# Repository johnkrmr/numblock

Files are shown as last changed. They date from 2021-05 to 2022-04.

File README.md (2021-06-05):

# Numblock #
A small 4x5 diy keypad to get into pcb design and custom keyboards.

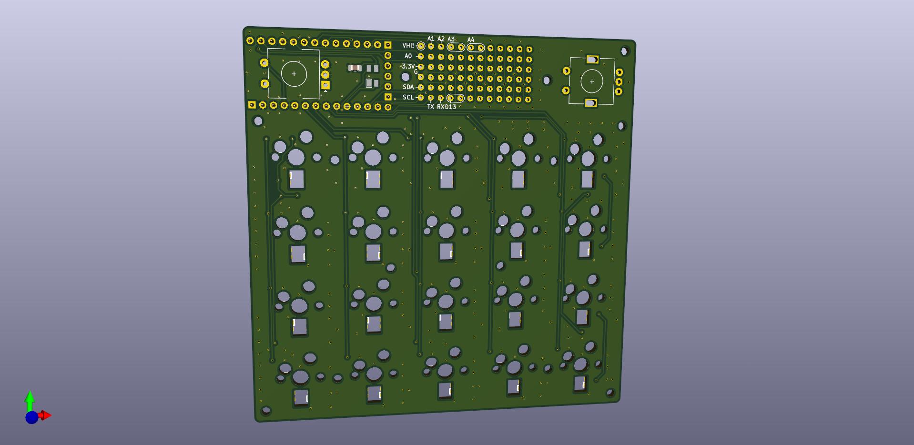
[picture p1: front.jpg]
pcb front
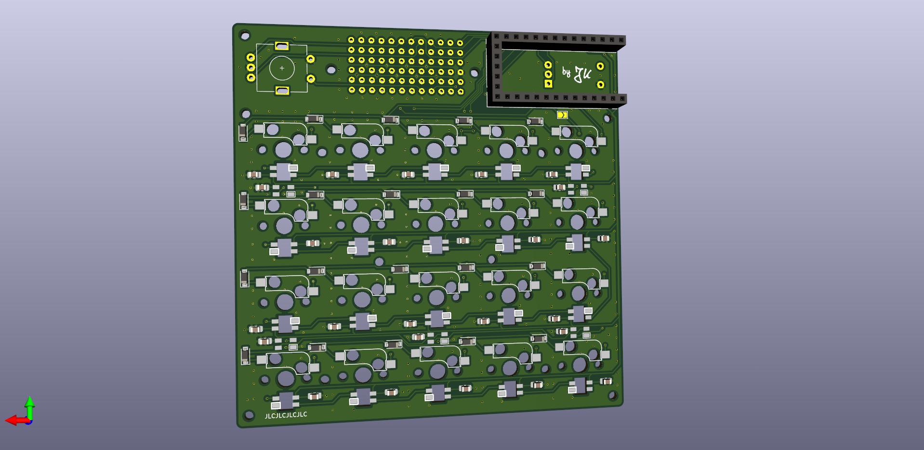
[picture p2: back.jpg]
pcb back
 

## IMPORTANT ##
PCB not tested yet. There's no guarantee that it will work right now!  
Front panel needed to mount 3-pin switches. No files for that provided yet.  
Generally this README and the whole project is far away from being
complete.

## Features ##
- 4x5 keys (cherry mx compatible, hotswappable)
- compatible with variety of Adafruit ItsyBitsy boards:
	- 32u4 (3.3V 8MHz Version!)
	- M4
	- nRF52840
	- RP2040?
	- M0?
- up to 2 rotary encoders (optional)
- indicator RGB led (optional)
- RGB underglow (optional)
- RGB backlight (optional)
- i2c OLED-Display (optional)
- small 'prototyping' area with access to i2c, serial + some analog Pins

## Components ##
- PCB
- 20 1N4148W Diods (SOD123 package)
- 20 hotswap sockets for cherry mx compatible switches
- 20 cherry mx compatible switches (both 3 and 5 pin versions should
work)
- compatible ItsyBitsy controller (cf. features)
- 8 SK6812 mini *HW* RGB LEDs for underglow + top indicator led
- 20 SK6812 mini RGB LEDs for backlight
- 0.1μF 0805 capacitors for each RGB LED (cf. notes)
- up to 2 Alps EC11E rotary encoders
- i2c OLED display, [this
one](https://www.waveshare.com/wiki/0.91inch_OLED_Module) should fit perfectly
- front panel
- some sort of case or an extra back panel
- screws to hold the whole thing together
- rubber feet (otherwise typing won't be much fun)

## Notes ##
### Electronics ###
- 0.1μF capacitors are recommended according to the datasheet. There are many
designs without them. I do not know whether or not they are necessary.
- A resistor on the LED data line between the controller and the first led is
recommended. I forgot to add that on. Here as well many pcbs do not include
them. It should work. [Supposedly](https://learn.adafruit.com/adafruit-neopixel-uberguide/basic-connections) what could happen is that the first LED in the 'chain' gets fried every
once in a while.
- A wireless version could be achieved with the nRF52840 in combination with the [LiIon/LiPoly
Backpack](https://www.adafruit.com/product/2124).

### Software ###
- I experienced some form of 'ghosting' in the upper two rows when setting
columns to *high* and
reading from row pins with *internal pulldowns* (diodes
facing opposite way than shown in schematics). When holding 4
switches down in same row, the 5th one shows as constantly on or
continuously toggling. This does
not seam to appear when setting rows to *low* and reading from columns with *internal
pullups*. So I guess **use internal pullups** for scanning the matrix.

## Resources ##
- [Josef Adamcik's sofle
keyboard](https://josefadamcik.github.io/SofleKeyboard/)
- [KiCad Keyboard Tutorial](https://github.com/ruiqimao/keyboard-pcb-guide)

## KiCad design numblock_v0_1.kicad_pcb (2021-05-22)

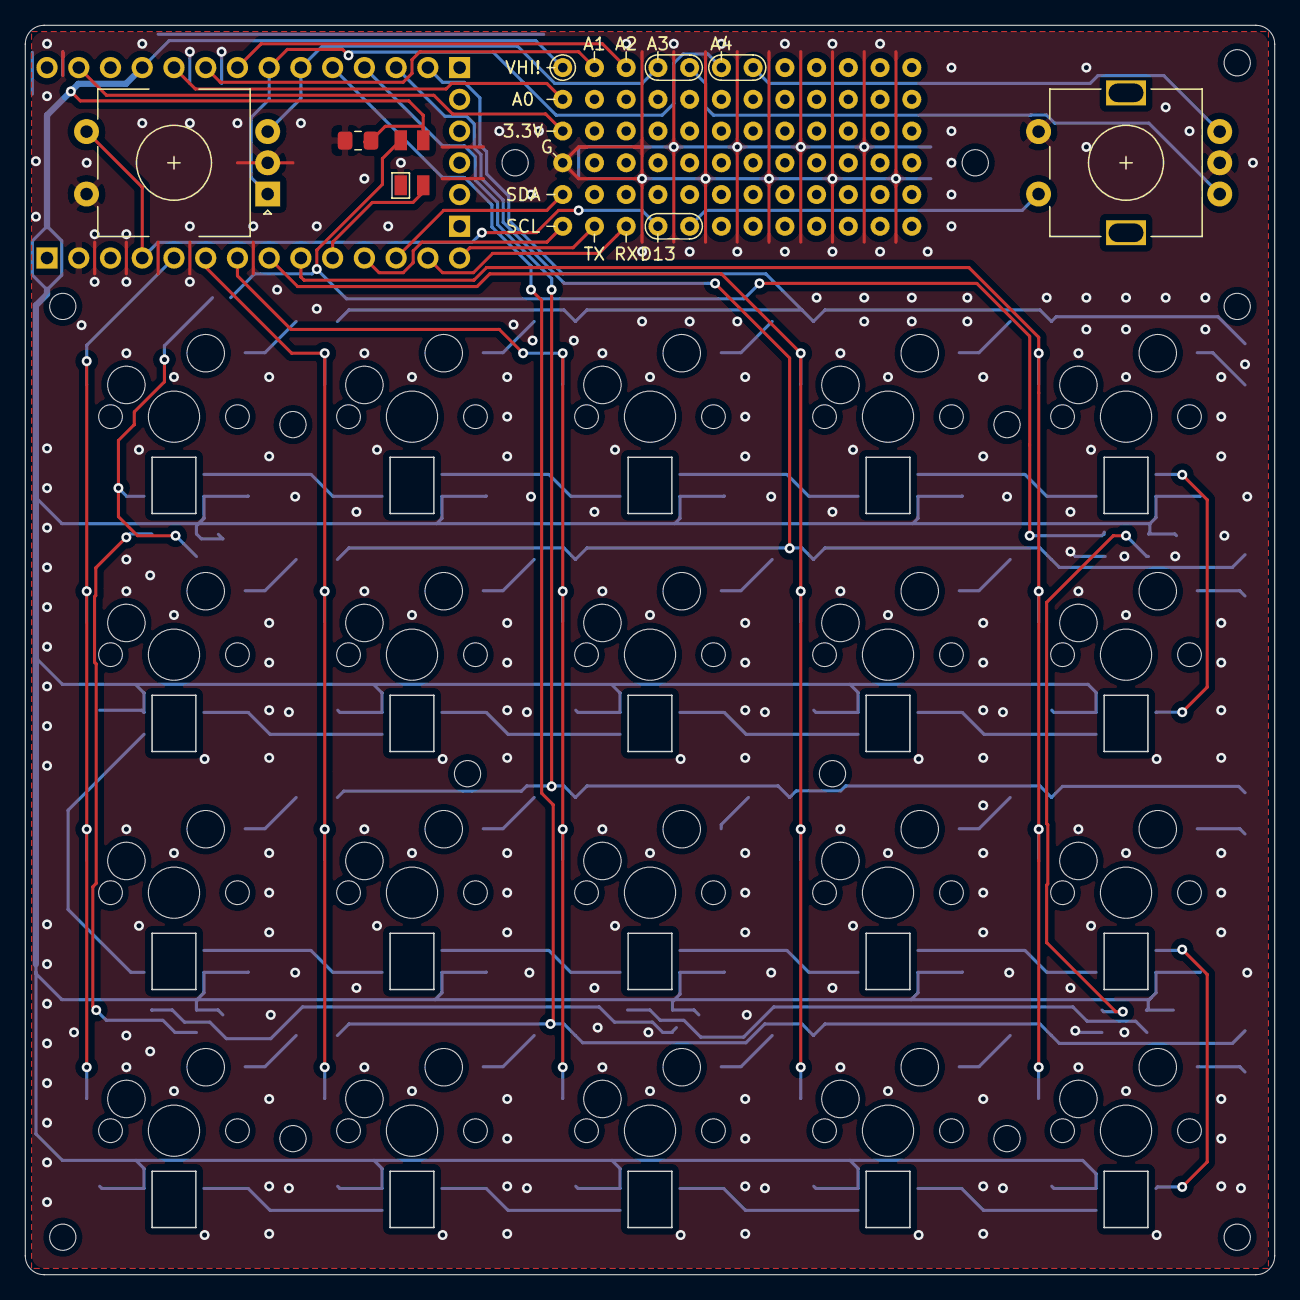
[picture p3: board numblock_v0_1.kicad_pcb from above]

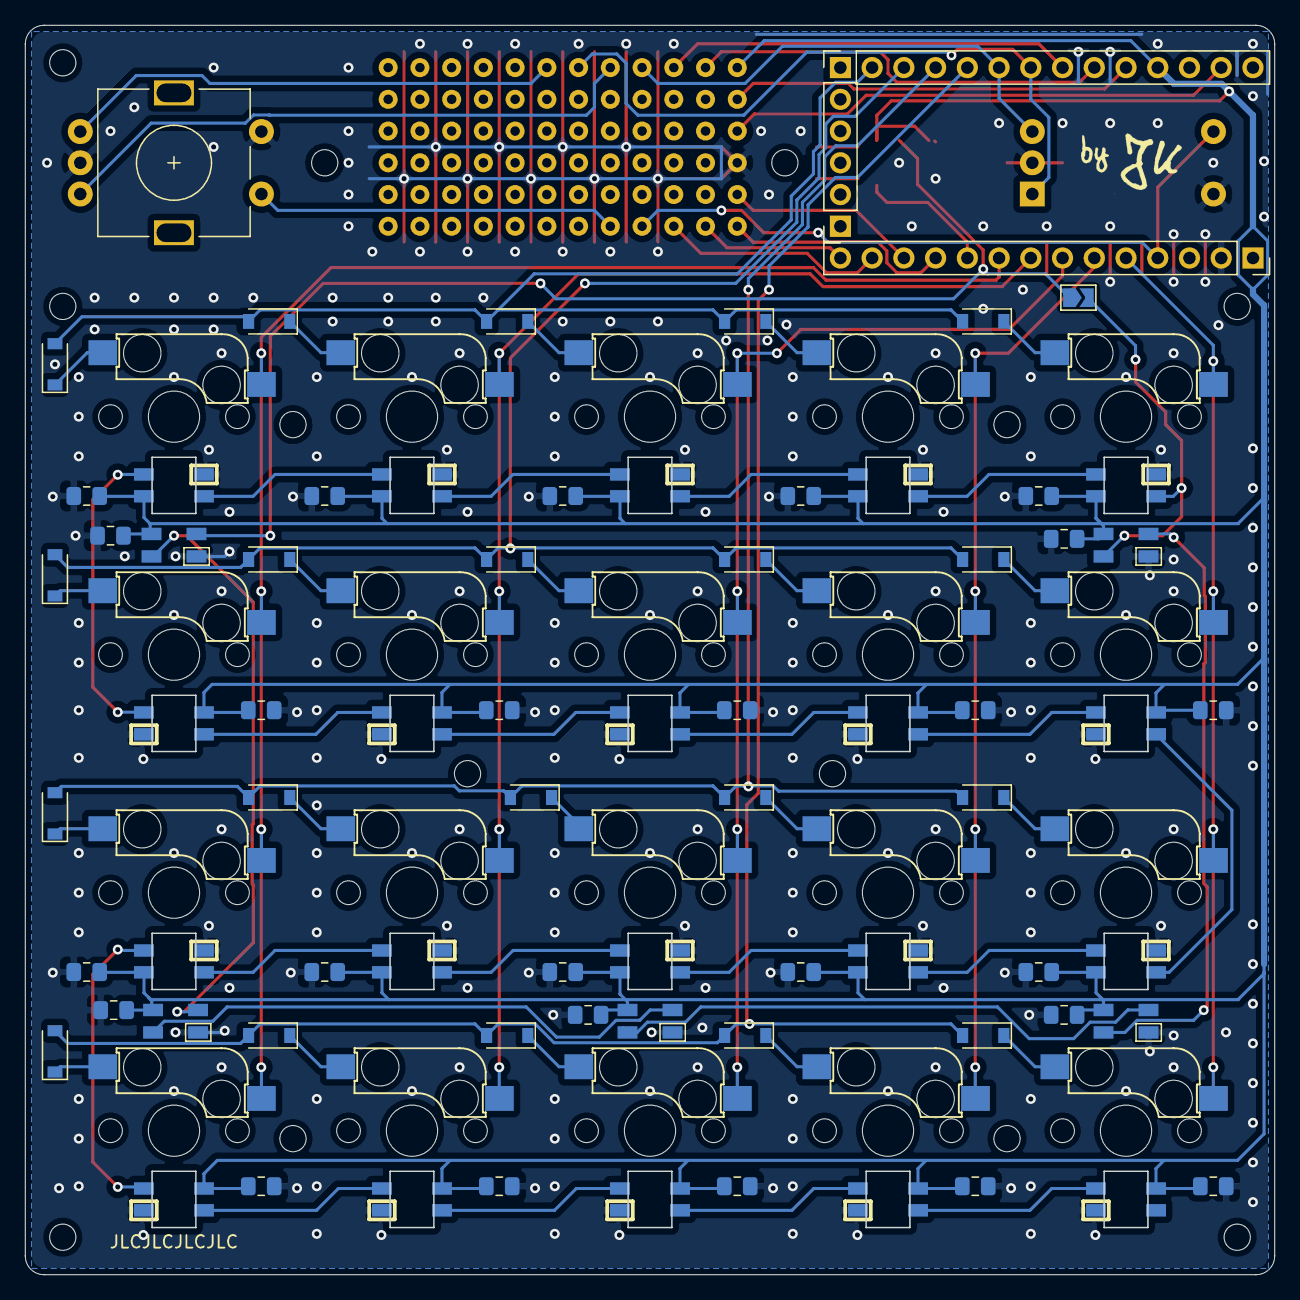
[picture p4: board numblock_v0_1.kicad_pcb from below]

Board: 2 copper layers, 100.0 x 100.0 mm, 106 parts (54 on the bottom side), 71 nets.

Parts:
C1, C2, C3, C4, C5, C6, C7, C8, C9, C10, C11, C12, C13, C14, C15, C16, C17, C18, C19, C20, C21, C22, C23, C24, C25, C26: C; C_0805_2012Metric_Pad1.18x1.45mm_HandSolder
D1, D2, D3, D4, D5, D6, D7, D8, D9, D10, D11, D12, D13, D14, D15, D16, D17, D18, D19, D20: D; D_SOD-123
D21, D22, D23, D24, D25, D26: SK6812MINI; LED_SK6812MINI_HS
H1, H2, H3, H4, H5, H6, H7, H8, H9, H10, H11, H12, H13, H14, H15: MountingHole_Pad; hole_30mil
J1, J2: Conn_01x14_Female; PinSocket_1x14_P2.54mm_Vertical
J3: Conn_01x05_Female; PinSocket_1x05_P2.54mm_Vertical
JP1: Jumper_2_Open; SolderJumper-2_P1.3mm_Open_TrianglePad1.0x1.5mm
SW1, SW2, SW3, SW4, SW5, SW11, SW12, SW13, SW14, SW15: SW_PUSH-MX_W_LED; SK6812MINI_and_cherry_oneside_ledflipped
SW6, SW7, SW8, SW9, SW10, SW16, SW17, SW18, SW19, SW20: SW_PUSH-MX_W_LED; SK6812MINI_and_cherry_oneside
SW21: Rotary_Encoder_Switch; RotaryEncoder_Alps_EC11E-Switch_Vertical_H20mm_NoMountingHo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
SW22: Rotary_Encoder_Switch; RotaryEncoder_Alps_EC11E-Switch_Vertical_H20mm-keebio_modif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
TH1, TH1#2, TH1#3, TH1#4, TH1#5, TH1#6, TH1#7, TH1#8, TH1#9, TH1#10, TH1#11, TH1#12, TH1#13: HOLE; MountingHole_2.1mm

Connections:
+3V3: H2.1, J2.13
+5V: C1.1, C2.1, C3.1, C4.1, C5.1, C6.1, C7.1, C8.1, C9.1, C10.1, C11.1, C12.1, C13.1, C14.1, C15.1, C16.1, C17.1, C18.1, C19.1, C20.1, C21.1, C22.1, C23.1, C24.1, C25.1, C26.1, D21.4, D22.4, D23.4, D24.4, D25.4, D26.4, J2.11, SW1.4, SW2.4, SW3.4, SW4.4, SW5.4, SW6.4, SW7.4, SW8.4, SW9.4, SW10.4, SW11.4, SW12.4, SW13.4, SW14.4, SW15.4, SW16.4, SW17.4, SW18.4, SW19.4, SW20.4
/A0: H7.1, J2.10
/A1: H8.1, J2.9
/A2: H15.1, J2.8
/C1: J1.5, SW1.5, SW6.5, SW11.5, SW16.5
/C2: J1.6, SW2.5, SW7.5, SW12.5, SW17.5
/C3: J1.7, SW3.5, SW8.5, SW13.5, SW18.5
/C4: J1.8, SW4.5, SW9.5, SW14.5, SW19.5
/C5: J1.9, SW5.5, SW10.5, SW15.5, SW20.5
/LED: D26.3, J1.10
/R1: D1.2, D2.2, D3.2, D4.2, D5.2, J2.2
/R2: D6.2, D7.2, D8.2, D9.2, D10.2, J2.3
/R3: D11.2, D12.2, D13.2, D14.2, D15.2, J2.4
/R4: D16.2, D17.2, D18.2, D19.2, D20.2, J2.5
/RX: H5.1, J1.14
/Rot1: H9.1, J2.7, SW21.A
/Rot2: H13.1, J2.6, SW21.B
/SCL: H4.1, J1.11
/SDA: H3.1, J1.12
/SW: H12.1, J1.4, SW21.S1
/TX: H6.1, J1.13
/leds/backlight: D25.1, JP1.2, SW1.3
/leds/led_pin: D21.3, D26.1, JP1.1
GND: C1.2, C2.2, C3.2, C4.2, C5.2, C6.2, C7.2, C8.2, C9.2, C10.2, C11.2, C12.2, C13.2, C14.2, C15.2, C16.2, C17.2, C18.2, C19.2, C20.2, C21.2, C22.2, C23.2, C24.2, C25.2, C26.2, D21.2, D22.2, D23.2, D24.2, D25.2, D26.2, H1.1, J1.2, SW1.2, SW2.2, SW3.2, SW4.2, SW5.2, SW6.2, SW7.2, SW8.2, SW9.2, SW10.2, SW11.2, SW12.2, SW13.2, SW14.2, SW15.2, SW16.2, SW17.2, SW18.2, SW19.2, SW20.2, SW21.C, SW21.S2, SW22.C, SW22.S1
unnamed: D1.1, SW1.6
unnamed: D2.1, SW2.6
unnamed: D3.1, SW3.6
unnamed: D4.1, SW4.6
unnamed: D5.1, SW5.6
unnamed: D6.1, SW6.6
unnamed: D7.1, SW7.6
unnamed: D8.1, SW8.6
unnamed: D9.1, SW9.6
unnamed: D10.1, SW10.6
unnamed: D11.1, SW11.6
unnamed: D12.1, SW12.6
unnamed: D13.1, SW13.6
unnamed: D14.1, SW14.6
unnamed: D15.1, SW15.6
unnamed: D16.1, SW16.6
unnamed: D17.1, SW17.6
unnamed: D18.1, SW18.6
unnamed: D19.1, SW19.6
unnamed: D20.1, SW20.6
unnamed: D21.1, D22.3
unnamed: D22.1, D23.3
unnamed: D23.1, D24.3
unnamed: D24.1, D25.3
unnamed: H10.1, SW22.A
unnamed: H11.1, SW22.S2
unnamed: H14.1, SW22.B
unnamed: SW1.1, SW2.3
unnamed: SW2.1, SW3.3
unnamed: SW3.1, SW4.3
unnamed: SW4.1, SW5.3
unnamed: SW6.3, SW7.1
unnamed: SW7.3, SW8.1
unnamed: SW8.3, SW9.1
unnamed: SW9.3, SW10.1
unnamed: SW5.1, SW10.3
unnamed: SW11.1, SW12.3
unnamed: SW6.1, SW11.3
unnamed: SW12.1, SW13.3
unnamed: SW13.1, SW14.3
unnamed: SW14.1, SW15.3
unnamed: SW15.1, SW20.3
unnamed: SW16.3, SW17.1
unnamed: SW17.3, SW18.1
unnamed: SW18.3, SW19.1
unnamed: SW19.3, SW20.1

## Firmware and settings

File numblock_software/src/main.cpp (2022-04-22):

#include <Arduino.h>
#include <Adafruit_NeoPixel_ZeroDMA.h>
#include <Adafruit_ZeroDMA.h>
#include <Adafruit_I2CDevice.h>
#include <Adafruit_NeoPixel.h>
#include <Adafruit_NeoMatrix_ZeroDMA.h>
#include <Adafruit_DotStar.h>
#include <leds.h>
#include <Keyboard.h>
#include <Encoder.h>

// Pin names
// Rows
#define R1 MISO
#define R2 MOSI
#define R3 SCK
#define R4 A5
// Columns
#define C1 12
#define C2 11
#define C3 10
#define C4 9
#define C5 7

// Left rotary encoder
#define RotSL 13
#define RotAL A4
#define RotBL A3

//Encoder encL(RotAL, RotBL, RotSL, 4);

// christmas lights
#define NUM_PIXELS 26
#define LED_PIN 5

#define NUM_ROWS 4
#define NUM_COLUMNS 5

const int row[NUM_ROWS] = {R1, R2, R3, R4};
const int column[NUM_COLUMNS] = {C1, C2, C3, C4, C5};
int matrix[NUM_ROWS][NUM_COLUMNS];
#ifndef PULLUP
int matrixOld[NUM_ROWS][NUM_COLUMNS] = {0};
#else
int matrixOld[NUM_ROWS][NUM_COLUMNS] = {1};
#endif
const uint8_t layout[NUM_ROWS][NUM_COLUMNS] = {
    {KEY_ESC, 'q', 'w', 'e', 'r'},
    {KEY_TAB, 'a', 's', 'd', 'f'},
    {KEY_LEFT_SHIFT, '>', 'y', 'x', 'c'},
    {KEY_LEFT_CTRL, KEY_LEFT_GUI, KEY_LEFT_ALT, 'b', ' '}};

const uint8_t layout2[NUM_ROWS][NUM_COLUMNS] = {
    {'7', '8', '9', KEY_DELETE, KEY_BACKSPACE},
    {'4', '5', '6', '-', '/'},
    {'1', '2', '3', '+', '*'},
    {'0', ',', '.', ' ', KEY_RETURN}};

uint8_t layer = 0;

int matrixInterrupts = 0;

Leds led = Leds();

//declare Functions
void scanMatrix();

void encoderRotation();

void mute();

void change_layer();

uint32_t randomColor();

void getKeys();

// For direct use of USB HID (yes, 3 is left out)
const uint8_t kHID_ReportID_Mouse = 1;
const uint8_t kHID_ReportID_Keyboard = 2;
const uint8_t kHID_ReportID_ConsumerControl = 4;
const uint8_t kHID_ReportID_SystemControl = 5;
const uint8_t kHID_ReportID_Gamepad = 6;
const uint8_t kHID_ReportID_MouseAbsolute = 7;
const uint8_t kHID_ReportID_NKRO_keyboard = 8;
const uint8_t kHID_ReportID_TeensyKeyboard = 9;
const uint8_t kHID_ReportID_SurfaceDial = 10;
const uint8_t kHID_ReportID_Telephony = 11;

// For use in "Consumer Control". They are bit coded.
const uint8_t VOLUME_UP = 1 << 0;      // Bit 0
const uint8_t VOLUME_DOWN = 1 << 1;    // Bit 1
const uint8_t VOLUME_MUTE = 1 << 2;    // Bit 2
const uint8_t MEDIA_PAUSE = 1 << 3;    // Bit 3
const uint8_t MEDIA_STOP = 1 << 4;     // Bit 4
const uint8_t MEDIA_NEXT = 1 << 5;     // Bit 5
const uint8_t MEDIA_PREVIOUS = 1 << 6; // Bit 6

static const uint8_t HID_ReportDescriptor_ConsumerControl[] PROGMEM =
    {
        0x05, 0x0c,                          // Usage Page ("Consumer Devices")
        0x09, 0x01,                          // Usage (Consumer Control)
        0xa1, 0x01,                          // Collection (Application)
        0x85, kHID_ReportID_ConsumerControl, // "Report ID"
        0x15, 0x00,                          // Logical Minimum (0)
        0x25, 0x01,                          // Logical Maximum (1)
        0x09, 0xe9,                          // Usage (Volume Up)
        0x09, 0xea,                          // Usage (Volume Down)
        0x75, 0x01,                          // Report Size (1)
        0x95, 0x02,                          // Report Count (2)
        0x81, 0x06,                          // Input (Data, Variable, Relative)

        0x09, 0xe2, // Usage (Mute)
        0x95, 0x01, // Report Count (1)
        0x81, 0x06, // Input (Data, Variable, Relative)

        0x09, 0xb0, // Usage (Play)
        0x95, 0x01, // Report Count (1)
        0x81, 0x06, // Input (Data, Variable, Relative)

        0x09, 0xb1, // Usage (Pause)
        0x95, 0x01, // Report Count (1)
        0x81, 0x06, // Input (Data, Variable, Relative)

        0x09, 0xb7, // Usage (Stop)
        0x95, 0x01, // Report Count (1)
        0x81, 0x06, // Input (Data, Variable, Relative)

        0x09, 0xb5, // Usage (Next)
        0x95, 0x01, // Report Count (1)
        0x81, 0x06, // Input (Data, Variable, Relative)

        0x09, 0xb6, // Usage (Previous)
        0x95, 0x01, // Report Count (1)
        0x81, 0x06, // Input (Data, Variable, Relative)

        0x09, 0xb3, // Usage (Fast Forward)
        0x95, 0x01, // Report Count (1)
        0x81, 0x06, // Input (Data, Variable, Relative)

        0x09, 0xb4, // Usage (Rewind)
        0x95, 0x01, // Report Count (1)
        0x81, 0x06, // Input (Data, Variable, Relative)

        0x95, 0x06, // Report Count (6) Number of bits remaining in byte
        0x81, 0x07, // Input (Constant, Variable, Relative)
        0xc0        // End Collection
};                  // Table for USB HID "Consumer Control" (for audio volume control, etc.)

/*const uint8_t kTelephoneMute = 1 << 0;   // Bit 0
const uint8_t kTelephoneDrop = 1 << 1; // Bit 1
static const uint8_t HID_ReportDescriptor_Telephony[] PROGMEM =
    {
        0x05, 0x0b,                          // Usage Page ("Telephony Device")
        0x09, 0x06,                          // Usage (Programmable Button)
        0xa1, 0x01,                          // Collection (Application)
        0x85, kHID_ReportID_Telephony,       // "Report ID"
        0x15, 0x00,                          // Logical Minimum (0)
        0x25, 0x01,                          // Logical Maximum (1)
        0x09, 0x2F,                          // Usage (Phone Mute)
        0x09, 0x26,                          // Usage (Drop)
        0x75, 0x01,                          // Report Size (1)
        0x95, 0x02,                          // Report Count (2)
        0x81, 0x06,                          // Input (Data, Variable, Relative)

        0x95, 0x0E, // Report Count (14) Number of bits remaining in byte
        0x81, 0x07, // Input (Constant, Variable, Relative)
        0xc0        // End Collection
};                  // Table for USB HID "Telephony Device" (for audio volume control, etc.)
*/

void setup()
{
  //Serial.begin(115200);

  // Setup LEDs
  led.begin();
  led.setBrightness(50);
  led.updateAll();

  // init Keyboard
  Keyboard.begin();

  // add media keys
  static HIDSubDescriptor node(HID_ReportDescriptor_ConsumerControl, sizeof(HID_ReportDescriptor_ConsumerControl));
  HID().AppendDescriptor(&node);
  /*static HIDSubDescriptor node1(HID_ReportDescriptor_Telephony, sizeof(HID_ReportDescriptor_Telephony));
  HID().AppendDescriptor(&node1);*/

  // setup and init Encoder
  //encL.setAccelerationEnabled(true);
  attachInterrupt(RotSL, change_layer, RISING);
  /*attachInterrupt(RotAL, encL.service(), CHANGE);
  attachInterrupt(RotBL, encL.service(), CHANGE);*/

  // init Matrix Pins
  pinMode(R1, OUTPUT);
  pinMode(R2, OUTPUT);
  pinMode(R3, OUTPUT);
  pinMode(R4, OUTPUT);
  digitalWrite(R1, LOW);
  digitalWrite(R2, LOW);
  digitalWrite(R3, LOW);
  digitalWrite(R4, LOW);
  pinMode(C1, INPUT_PULLUP);
  pinMode(C2, INPUT_PULLUP);
  pinMode(C3, INPUT_PULLUP);
  pinMode(C4, INPUT_PULLUP);
  pinMode(C5, INPUT_PULLUP);

  // init Matrix interrupts
  /*attachInterrupt(R1, scanMatrix, CHANGE);
  attachInterrupt(R2, scanMatrix, CHANGE);
  attachInterrupt(R3, scanMatrix, CHANGE);
  attachInterrupt(R4, scanMatrix, CHANGE);
*/

  //Serial.println("Initialisation complete");
}

void loop()
{
  scanMatrix();
  getKeys();
  /*for (int i = 0; i < NUM_ROWS; i++)
  {
    for (int j = 0; j < NUM_COLUMNS; j++)
    {
      Serial.print(matrix[i][j]);
    }
    Serial.print('\n');
  }*/
  //encoderRotation();

  delay(10);
  /*uint16_t i;

  // 'Color wipe' across all pixels
  for(uint32_t c = 0xFF0000; c; c >>= 8) { // Red, green, blue
    for(i=0; i<pixels.numPixels(); i++) {
      pixels.setPixelColor(i, c);
      pixels.show();
      delay(50);
    }
  }

  // Rainbow cycle
  uint32_t elapsed, t, startTime = micros();
  for(;;) {
    t       = micros();
    elapsed = t - startTime;
    if(elapsed > 5000000) break; // Run for 5 seconds
    uint32_t firstPixelHue = elapsed / 32;
    for(i=0; i<pixels.numPixels(); i++) {
      uint32_t pixelHue = firstPixelHue + (i * 65536L / pixels.numPixels());
      pixels.setPixelColor(i, pixels.gamma32(pixels.ColorHSV(pixelHue)));
    }
    pixels.show();
  }*/
}

void scanMatrix()
{
  digitalWrite(C1, HIGH);
  digitalWrite(C2, HIGH);
  digitalWrite(C3, HIGH);
  digitalWrite(C4, HIGH);
  digitalWrite(C5, HIGH);
  for (int i = 0; i < NUM_ROWS; i++)
  {
    digitalWrite(row[i], LOW);
    for (int j = 0; j < NUM_COLUMNS; j++)
    {
      matrix[i][j] = digitalRead(column[j]);
    }
    digitalWrite(row[i], HIGH);
  }

  digitalWrite(C1, LOW);
  digitalWrite(C2, LOW);
  digitalWrite(C3, LOW);
  digitalWrite(C4, LOW);
  digitalWrite(C5, LOW);
}

/*void encoderRotation()
{
  int16_t encSteps = encL.getValue();
  while (encSteps != 0)
  {
    //Serial.printf("Encoder Value: %d", encSteps);
    if (encSteps > 0)
    {
      Keyboard.write(KEY_DOWN_ARROW);
      encSteps--;
    }
    else
    {
      Keyboard.write(KEY_UP_ARROW);
      encSteps++;
    }
  }

  Encoder::Button buttonState = encL.getButton();
  if (buttonState != 0)
  {
    switch (buttonState)
    {
    case Encoder::Open: //0
      break;

    case Encoder::Closed: //1
      break;

    case Encoder::Pressed: //2
      break;

    case Encoder::Held: //3
      break;

    case Encoder::Released: //4
      break;

    case Encoder::Clicked: //5
      break;

    case Encoder::DoubleClicked: //6
      break;
    }
  }
}*/

void mute()
{
  Keyboard.press(KEY_LEFT_CTRL);
  delay(1);
  uint8_t data[2];
  data[0] = VOLUME_MUTE;
  data[1] = 0;
  HID().SendReport(kHID_ReportID_ConsumerControl, data, 2);
  delay(1);
  Keyboard.releaseAll();
  /*uint8_t data[2];
  data[0] = kTelephoneMute;
  data[1] = 0b0;
  HID().SendReport(kHID_ReportID_Telephony, data, 1);*/
}

void change_layer()
{
  layer = layer==0?1:0;
  Serial.println(layer);
}

uint32_t randomColor()
{
  return rand() % 0xFFFFFF;
}

void getKeys()
{
  for (int i = 0; i < NUM_ROWS; i++)
  {
    for (int j = 0; j < NUM_COLUMNS; j++)
    {
      if (i==3&&j==1)
      {
        if (matrix[i][j] == 0 && matrixOld[i][j] == 1)
        {
          mute();
        }
      }
      else{
        if (matrix[i][j] == 0 && matrixOld[i][j] == 1)
        {
          Keyboard.press(layout[i][j]);
        }
        else if (matrix[i][j] == 1 && matrixOld[i][j] == 0)
        {
          Keyboard.release(layout[i][j]);
        }
      }
      matrixOld[i][j] = matrix[i][j];
    }
  }
}

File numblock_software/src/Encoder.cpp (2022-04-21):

// ----------------------------------------------------------------------------
// Rotary Encoder Driver with Acceleration
// Supports Click, DoubleClick, Long Click
//
// (c) 2010 karl@pitrich.com
// (c) 2014 karl@pitrich.com
// 
// Timer-based rotary encoder logic by Peter Dannegger
// http://www.mikrocontroller.net/articles/Drehgeber
// ----------------------------------------------------------------------------

#include "Encoder.h"

// ----------------------------------------------------------------------------
// Button configuration (values for 1ms timer service calls)
//
#define ENC_BUTTONINTERVAL    10  // check button every x milliseconds, also debouce time

// ----------------------------------------------------------------------------
// Acceleration configuration (for 1000Hz calls to ::service())
//
#define ENC_ACCEL_TOP      3072   // max. acceleration: *12 (val >> 8)
#define ENC_ACCEL_INC        25
#define ENC_ACCEL_DEC         2

// ----------------------------------------------------------------------------

#if ENC_DECODER != ENC_NORMAL
#  if ENC_HALFSTEP
     // decoding table for hardware with flaky notch (half resolution)
     const int8_t Encoder::table[16] __attribute__((__progmem__)) = { 
       0, 0, -1, 0, 0, 0, 0, 1, 1, 0, 0, 0, 0, -1, 0, 0 
     };    
#  else
     // decoding table for normal hardware
     const int8_t Encoder::table[16] __attribute__((__progmem__)) = { 
       0, 1, -1, 0, -1, 0, 0, 1, 1, 0, 0, -1, 0, -1, 1, 0 
     };    
#  endif
#endif

// ----------------------------------------------------------------------------

Encoder::Encoder(int8_t A, int8_t B, int8_t BTN, uint8_t stepsPerNotch, bool active)
  : doubleClickEnabled(true),buttonHeldEnabled(true), accelerationEnabled(true),
    delta(0), last(0), acceleration(0),
    button(Open), steps(stepsPerNotch),
    pinA(A), pinB(B), pinBTN(BTN), pinsActive(active)
#ifndef WITHOUT_BUTTON
    , analogInput(false)
#endif
{
  pinMode_t configType = (pinsActive == LOW) ? INPUT_PULLUP : INPUT;
  if (pinA >= 0) {pinMode(pinA, configType);}
  if (pinB >= 0) {pinMode(pinB, configType);}
#ifndef WITHOUT_BUTTON
  if (pinBTN >= 0) {pinMode(pinBTN, configType);}
#endif
  
  if (digitalRead(pinA) == pinsActive) {
    last = 3;
  }

  if (digitalRead(pinB) == pinsActive) {
    last ^=1;
  }
}

// ----------------------------------------------------------------------------
#ifndef WITHOUT_BUTTON


// Depricated.  Use DigitalButton instead
Encoder::Encoder(int8_t BTN, bool active)
  : doubleClickEnabled(true),buttonHeldEnabled(true), accelerationEnabled(true),
    delta(0), last(0), acceleration(0),
    button(Open), steps(1), analogInput(false),
    pinA(-1), pinB(-1), pinBTN(BTN), pinsActive(active)
{
  pinMode_t configType = (pinsActive == LOW) ? INPUT_PULLUP : INPUT;
  if (pinBTN >= 0) {pinMode(pinBTN, configType);}
}

// ----------------------------------------------------------------------------
// Constructor for using digital input as a button

DigitalButton::DigitalButton(int8_t BTN, bool active) : Encoder(BTN, active)

{

}

// ----------------------------------------------------------------------------
// Constructor for using analog input range as a button

AnalogButton::AnalogButton(int8_t BTN, int16_t rangeLow, int16_t rangeHigh) : Encoder(BTN, (bool)false)
{
  pinMode(pinBTN, INPUT);
  
  anlogActiveRangeLow = rangeLow;
  anlogActiveRangeHigh = rangeHigh;
  analogInput = true;
  
  if (anlogActiveRangeLow > anlogActiveRangeHigh) {    // swap values if provided in the wrong order
	  int16_t t = anlogActiveRangeLow;
	  anlogActiveRangeLow = anlogActiveRangeHigh;
	  anlogActiveRangeHigh = t;
  }
}
#endif

// ----------------------------------------------------------------------------
// call this every 1 millisecond via timer ISR
//
voidFuncPtr Encoder::service(void)
{
  bool moved = false;

  if (pinA >= 0 && pinB >= 0) {
  if (accelerationEnabled) { // decelerate every tick
    acceleration -= ENC_ACCEL_DEC;
    if (acceleration & 0x8000) { // handle overflow of MSB is set
      acceleration = 0;
    }
  }

#if ENC_DECODER == ENC_FLAKY
  last = (last << 2) & 0x0F;

  if (digitalRead(pinA) == pinsActive) {
    last |= 2;
  }

  if (digitalRead(pinB) == pinsActive) {
    last |= 1;
  }

  int8_t tbl = pgm_read_byte(&table[last]); 
  if (tbl) {
    delta += tbl;
    moved = true;
  }
#elif ENC_DECODER == ENC_NORMAL
  int8_t curr = 0;

  if (digitalRead(pinA) == pinsActive) {
    curr = 3;
  }

  if (digitalRead(pinB) == pinsActive) {
    curr ^= 1;
  }
  
  int8_t diff = last - curr;

  if (diff & 1) {            // bit 0 = step
    last = curr;
    delta += (diff & 2) - 1; // bit 1 = direction (+/-)
    moved = true;    
  }
#else
# error "Error: define ENC_DECODER to ENC_NORMAL or ENC_FLAKY"
#endif

  if (accelerationEnabled && moved) {
    // increment accelerator if encoder has been moved
    if (acceleration <= (ENC_ACCEL_TOP - ENC_ACCEL_INC)) {
      acceleration += ENC_ACCEL_INC;
    }
  }
}
  // handle button
  //
#ifndef WITHOUT_BUTTON
  unsigned long currentMillis = millis();
  if (currentMillis < lastButtonCheck) lastButtonCheck = 0;        // Handle case when millis() wraps back around to zero
  if ((pinBTN > 0 || (pinBTN == 0 && buttonOnPinZeroEnabled))        // check button only, if a pin has been provided
      && ((currentMillis - lastButtonCheck) >= ENC_BUTTONINTERVAL))            // checking button is sufficient every 10-30ms
  { 
    lastButtonCheck = currentMillis;

    bool pinRead = getPinState();
    
    if (pinRead == pinsActive) { // key is down
      keyDownTicks++;
      if ((keyDownTicks > (buttonHoldTime / ENC_BUTTONINTERVAL)) && (buttonHeldEnabled)) {
        button = Held;
      }
    }

    if (pinRead == !pinsActive) { // key is now up
      if (keyDownTicks > 1) {               //Make sure key was down through 1 complete tick to prevent random transients from registering as click
        if (button == Held) {
          button = Released;
          doubleClickTicks = 0;
        }
        else {
          #define ENC_SINGLECLICKONLY 1
          if (doubleClickTicks > ENC_SINGLECLICKONLY) {   // prevent trigger in single click mode
            if (doubleClickTicks < (buttonDoubleClickTime / ENC_BUTTONINTERVAL)) {
              button = DoubleClicked;
              doubleClickTicks = 0;
            }
          }
          else {
            doubleClickTicks = (doubleClickEnabled) ? (buttonDoubleClickTime / ENC_BUTTONINTERVAL) : ENC_SINGLECLICKONLY;
          }
        }
      }

      keyDownTicks = 0;
    }
  
    if (doubleClickTicks > 0) {
      doubleClickTicks--;
      if (doubleClickTicks == 0) {
        button = Clicked;
      }
    }
  }
#endif // WITHOUT_BUTTON

}

// ----------------------------------------------------------------------------
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

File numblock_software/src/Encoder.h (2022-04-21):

// ----------------------------------------------------------------------------
// Rotary Encoder Driver with Acceleration
// Supports Click, DoubleClick, Long Click
//
// (c) 2010 karl@pitrich.com
// (c) 2014 karl@pitrich.com
// 
// Timer-based rotary encoder logic by Peter Dannegger
// http://www.mikrocontroller.net/articles/Drehgeber
// ----------------------------------------------------------------------------

#ifndef __have__Encoder_h__
#define __have__Encoder_h__

// ---Button defaults-------------------------------------------------------------

#define BTN_DOUBLECLICKTIME  400  // second click within 400ms
#define BTN_HOLDTIME        1000  // report held button after 1s


// ----------------------------------------------------------------------------

#include <stdint.h>
#if defined(__AVR__)
#include <avr/io.h>
#include <avr/interrupt.h>
#include <avr/pgmspace.h>
#endif
#include "Arduino.h"

// ----------------------------------------------------------------------------

#define ENC_NORMAL        (1 << 1)   // use Peter Danneger's decoder
#define ENC_FLAKY         (1 << 2)   // use Table-based decoder

// ----------------------------------------------------------------------------

#ifndef ENC_DECODER
#  define ENC_DECODER     ENC_NORMAL
#endif

#if ENC_DECODER == ENC_FLAKY
#  ifndef ENC_HALFSTEP
#    define ENC_HALFSTEP  1        // use table for half step per default
#  endif
#endif

// ----------------------------------------------------------------------------
#if    defined(__arm__) && (defined (__STM32F1__) || defined (__STM32F4__) )
  typedef WiringPinMode pinMode_t;
#else
  typedef uint8_t pinMode_t;
#endif

class Encoder
{
public:
  typedef enum Button_e {
    Open = 0,
    Closed,
    
    Pressed,
    Held,
    Released,
    
    Clicked,
    DoubleClicked
    
  } Button;

public:
  Encoder(int8_t A, int8_t B, int8_t BTN = -1, 
               uint8_t stepsPerNotch = 4, bool active = LOW);
			   
#ifndef WITHOUT_BUTTON
  explicit Encoder(int8_t BTN, bool active = false);   // Depricated.  Use Digtial Button instead

#endif

  voidFuncPtr service(void);  
  int16_t getValue(void);

#ifndef WITHOUT_BUTTON
public:
  Button getButton(void);
#endif

#ifndef WITHOUT_BUTTON
public:
  void setDoubleClickTime(uint16_t durationMilliseconds)
  {
    buttonDoubleClickTime = durationMilliseconds;
  }
  
public:
  void setHoldTime(uint16_t durationMilliseconds)
  {
    buttonHoldTime = durationMilliseconds;
  }
  
public:
  void setDoubleClickEnabled(const bool &d)
  {
    doubleClickEnabled = d;
  }

  const bool getDoubleClickEnabled()
  {
    return doubleClickEnabled;
  }
  
public:
  void setButtonHeldEnabled(const bool &d)
  {
    buttonHeldEnabled = d;
  }

  const bool getButtonHeldEnabled()
  {
    return buttonHeldEnabled;
  }
  
public:
  void setButtonOnPinZeroEnabled(const bool &d)
  {
    buttonOnPinZeroEnabled = d;
  }

  const bool getButtonOnPinZeroEnabled()
  {
    return buttonOnPinZeroEnabled;
  }
#endif

public:
  void setAccelerationEnabled(const bool &a)
  {
    accelerationEnabled = a;
    if (accelerationEnabled == false) {
      acceleration = 0;
    }
  }

  const bool getAccelerationEnabled() 
  {
    return accelerationEnabled;
  }

protected:
  int8_t pinA;
  int8_t pinB;
  int8_t pinBTN;
  bool pinsActive;
  volatile int16_t delta;
  volatile int16_t last;
  volatile uint8_t steps;
  volatile uint16_t acceleration;
  bool accelerationEnabled;
#if ENC_DECODER != ENC_NORMAL
  static const int8_t table[16];
#endif
#ifndef WITHOUT_BUTTON
  volatile Button button;
  bool doubleClickEnabled;
  bool buttonHeldEnabled;
  bool buttonOnPinZeroEnabled = false;
  bool analogInput = false;
  uint16_t keyDownTicks = 0;
  uint16_t doubleClickTicks = 0;
  uint16_t buttonHoldTime = BTN_HOLDTIME;
  uint16_t buttonDoubleClickTime = BTN_DOUBLECLICKTIME;
  unsigned long lastButtonCheck = 0;
  int16_t anlogActiveRangeLow = 0;
  int16_t anlogActiveRangeHigh = 0;
  bool getPinState();
#endif
};

#ifndef WITHOUT_BUTTON
class AnalogButton : public Encoder
{ 
  public:
    explicit AnalogButton(int8_t BTN, int16_t rangeLow, int16_t rangeHigh);  // Constructor for using analog input range as a button
};

class DigitalButton : public Encoder
{ 
  public:
    explicit DigitalButton(int8_t BTN, bool active = false);  // Constructor for using a button only
};

#endif

// ----------------------------------------------------------------------------

#endif // __have__Encoder_h__

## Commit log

2021-05-08 Initialer Commit
    [leds.sch, numblock_v0_1.kicad_pcb, numblock_v0_1.sch]
2021-05-08 Fixed missing gnd connections
    [numblock_v0_1.kicad_pcb]
2021-05-11 kinda done, about to add jumpers for rot. enc.
    [leds.sch, numblock_v0_1.kicad_pcb, numblock_v0_1.sch]
2021-05-11 done for tonight
    [numblock_v0_1.kicad_pcb, numblock_v0_1.sch]
2021-05-14 about to add underglow
    [leds.sch, numblock_v0_1.kicad_pcb, numblock_v0_1.sch]
2021-05-14 added top led and oled display support
    [leds.sch, numblock_v0_1.kicad_pcb, numblock_v0_1.sch]
2021-05-14 fixed display position
    [numblock_v0_1.kicad_pcb]
2021-05-14 moved display down
    [numblock_v0_1.kicad_pcb]
2021-05-14 fixed backlight leds; added holes
    [leds.sch, numblock_v0_1.kicad_pcb, numblock_v0_1.sch]
2021-05-14 mounting holes added
    [numblock_v0_1.kicad_pcb]
2021-05-22 replaced plated mountig holes to unplated; final touches before placing order
    [numblock_v0_1.kicad_pcb, numblock_v0_1.sch]
2021-05-22 added pcb renders
2021-05-23 added wireless note; fixed mistake
